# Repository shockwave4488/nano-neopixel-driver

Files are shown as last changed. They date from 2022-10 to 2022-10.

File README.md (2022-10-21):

# Nano NeoPixel driver
An all in one board for driving neopixel, or equivalent, led strips using an Arduino Nano

**WARNING: THIS BOARD IS 5V ONLY. APPLYING A HIGHER VOLTAGE WILL RESULT IN A DEAD ARDUINO AND LEDS**

Instructions for the jumpers on the back <br>
Adafruit recommends putting a 470 ohm resistor in series with the WS2812B data line. To acomodate both LED and GPIO signals, the back of the board has a resistor footprint and a solder jumper for each exposed DIO. Populate the resistor for DIO that will drive an LED signal, and solder the jumper for DIO that will be GPIO.

Assembly
1) Populatate the resistors and jumpers on the back as needed
2) Install the arduino
3) Attach wire or headers for Vin and the DIO
4) Install the capacitor

BOM <br>
1x Arduino Nano <br>
1x 1000uF Würth Elektronik 860010274015 (or comparable capacitor with same footprint) <br>
8x 470 ohm 0805 resistors <br>

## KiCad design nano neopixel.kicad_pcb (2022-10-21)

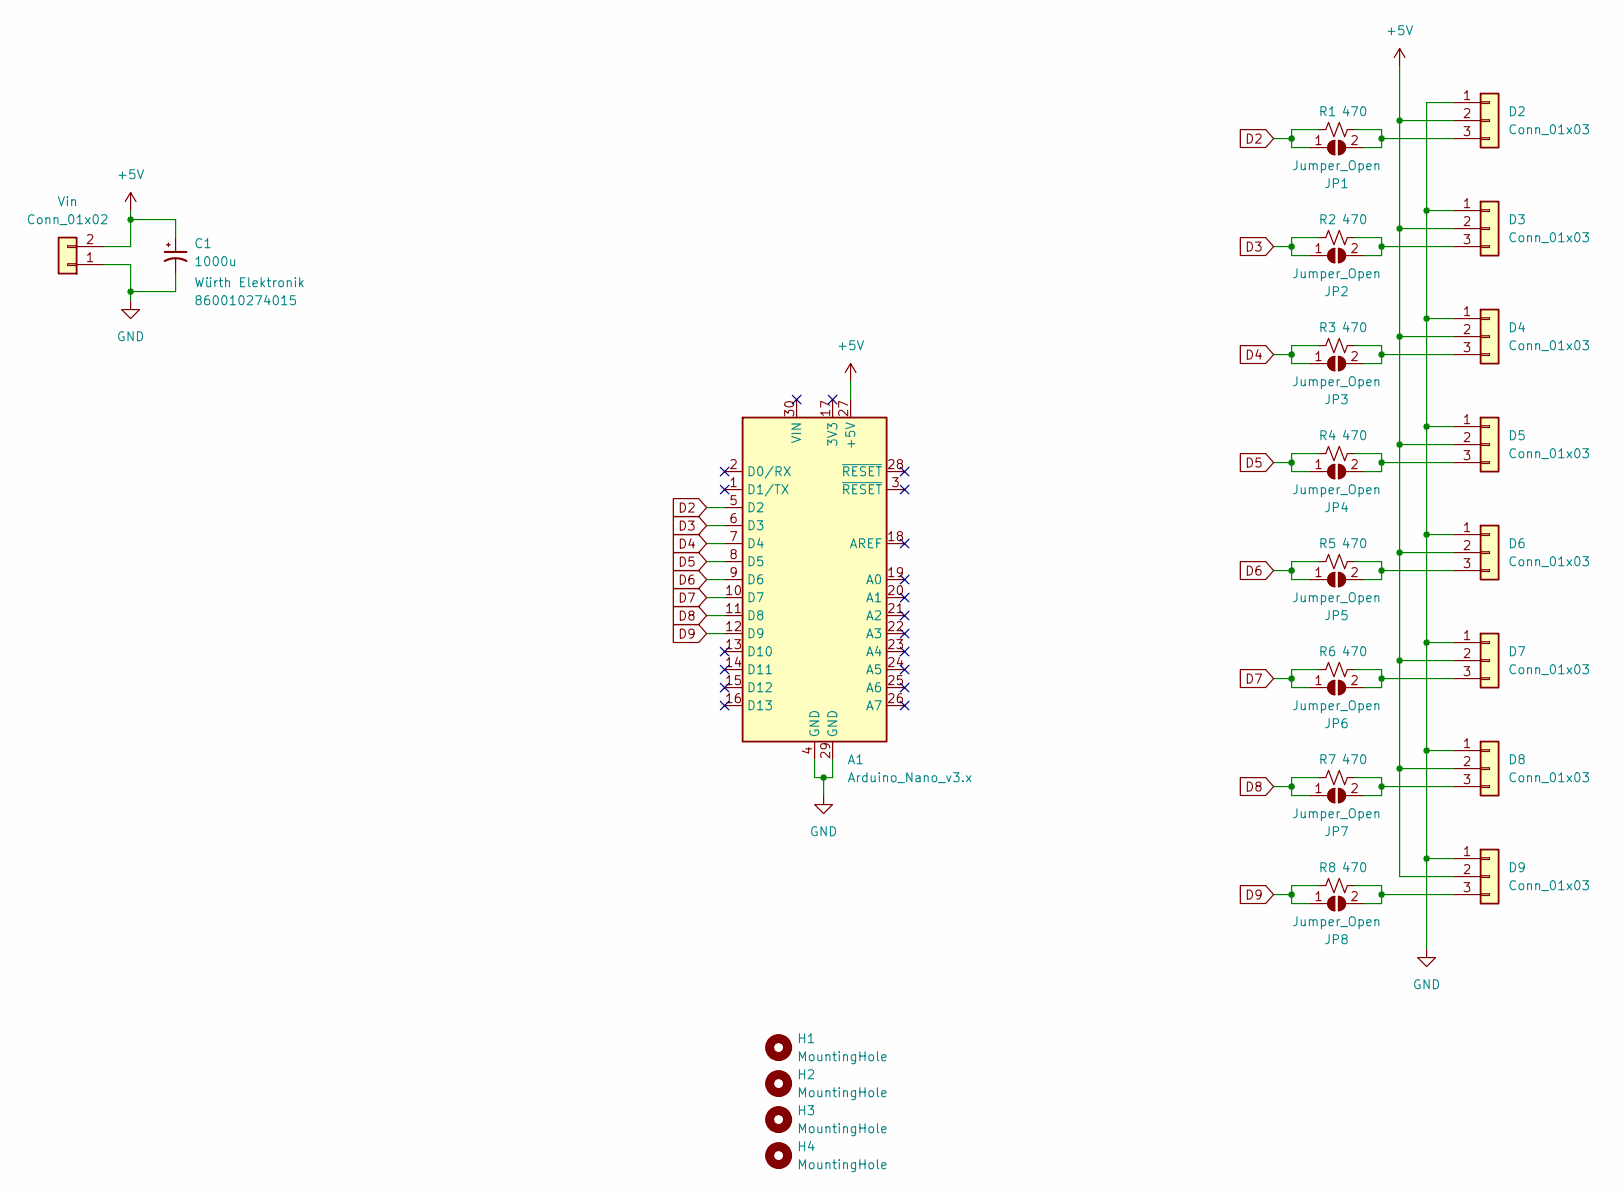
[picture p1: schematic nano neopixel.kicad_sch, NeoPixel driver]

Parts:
A1: Arduino_Nano_v3.x; Arduino_Nano
C1: 1000u; CP_Radial_D8.0mm_P3.50mm
D2, D3, D4, D5, D6, D7, D8, D9: Conn_01x03; PinHeader_1x03_P2.54mm_Vertical
H1, H2, H3, H4: MountingHole; MountingHole_3.2mm_M3
JP1, JP2, JP3, JP4, JP5, JP6, JP7, JP8: Jumper_Open; SolderJumper-2_P1.3mm_Open_Pad1.0x1.5mm
R1, R2, R3, R4, R5, R6, R7, R8: 470; R_0805_2012Metric
Vin: Conn_01x02; PinHeader_1x02_P2.54mm_Vertical

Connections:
+5V: A1.27 (+5V), C1.1, D2.2, D3.2, D4.2, D5.2, D6.2, D7.2, D8.2, D9.2, Vin.2
D2: A1.5 (D2), JP1.1 (A), R1.1
D3: A1.6 (D3), JP2.1 (A), R2.1
D4: A1.7 (D4), JP3.1 (A), R3.1
D5: A1.8 (D5), JP4.1 (A), R4.1
D6: A1.9 (D6), JP5.1 (A), R5.1
D7: A1.10 (D7), JP6.1 (A), R6.1
D8: A1.11 (D8), JP7.1 (A), R7.1
D9: A1.12 (D9), JP8.1 (A), R8.1
GND: A1.4 (GND), A1.29 (GND), C1.2, D2.1, D3.1, D4.1, D5.1, D6.1, D7.1, D8.1, D9.1, Vin.1
unnamed: D2.3, JP1.2 (B), R1.2
unnamed: D3.3, JP2.2 (B), R2.2
unnamed: D4.3, JP3.2 (B), R3.2
unnamed: D5.3, JP4.2 (B), R4.2
unnamed: D6.3, JP5.2 (B), R5.2
unnamed: D7.3, JP6.2 (B), R6.2
unnamed: D8.3, JP7.2 (B), R7.2
unnamed: D9.3, JP8.2 (B), R8.2

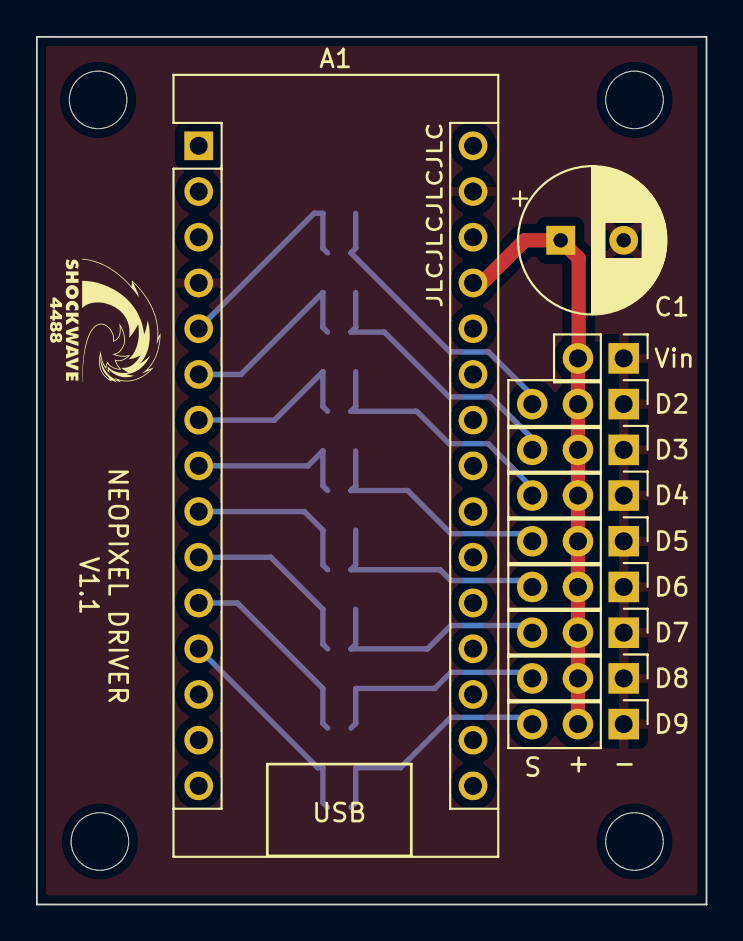
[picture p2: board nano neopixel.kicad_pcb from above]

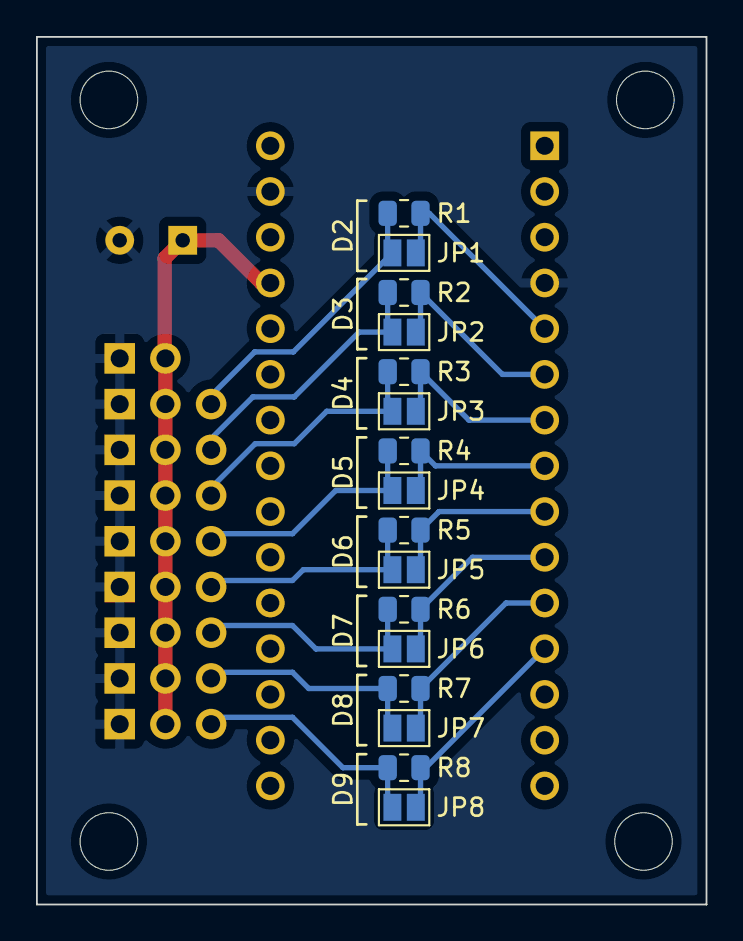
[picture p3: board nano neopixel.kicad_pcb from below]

Board: 2 copper layers, 37.2 x 48.2 mm, 31 parts (16 on the bottom side), 18 nets.

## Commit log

2022-10-21 completed layout
    [nano neopixel.kicad_pcb, nano neopixel.kicad_sch]
2022-10-21 added USB notation to the board
    [nano neopixel.kicad_pcb]
2022-10-21 Added instructions and bom
2022-10-21 Attempting to make the bom a list and make jumper instruction headder
2022-10-21 shifted the JLC order number designator away from the USB
    [nano neopixel.kicad_pcb]
